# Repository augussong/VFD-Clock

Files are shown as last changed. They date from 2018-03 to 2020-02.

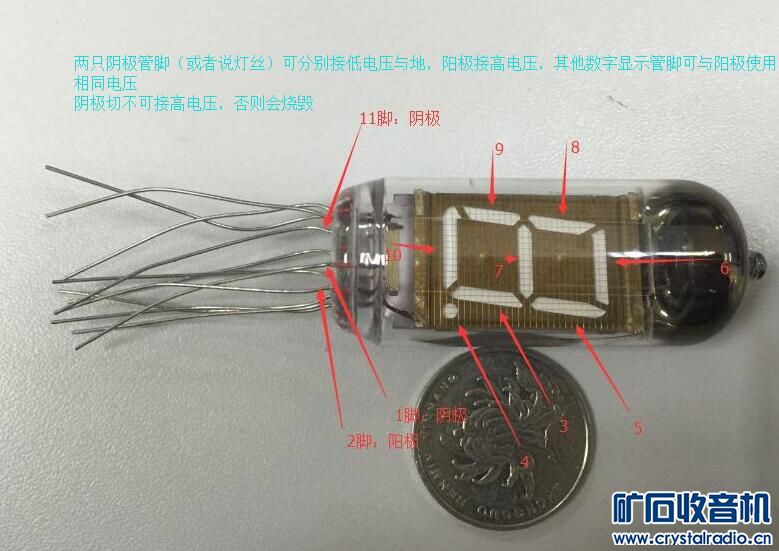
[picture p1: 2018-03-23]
Reference/管脚图.jpg

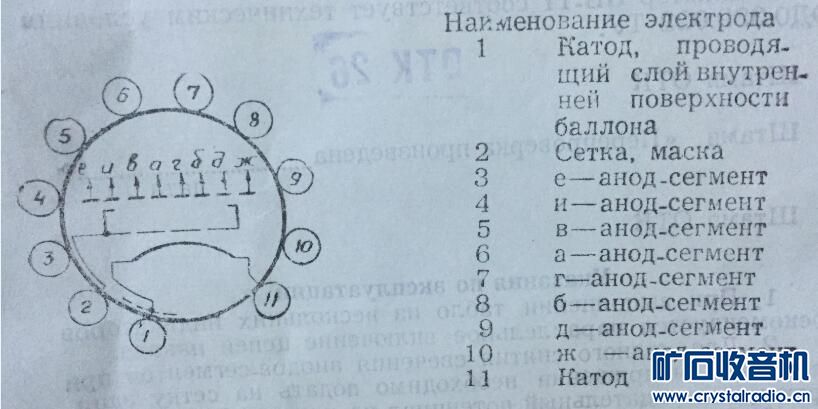
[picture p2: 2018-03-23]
Reference/管脚底视定义.jpg

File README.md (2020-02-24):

# VFD-Clock Designed By drinow
- 用IV-11制作的荧光数码管时钟

## 预计支持的功能
	1.USB连接
	2.温湿度显示
	3.RGB色彩变换
	4.静态驱动
	5.WiFi/蓝牙、红外控制
	6.uCOS-ii
	7.可以断电
	8.环境光感应

## 更新日志
- 2020.02.25更新
  - ESP8266基本功能已完成
  - 需要重新设计电源电路
  - 需要将USB更换为TYPEC，并重新调整外壳尺寸
  - 需要删除TM1812，因为无法达到100%占空比，无法实现动态驱动
- 2019.04.26更新
	+ 删除CH340晶振，并改为CH340C芯片
	+ 修改温湿度传感器位置到USB口下方
	+ 删去复位按键
	+ 其他细节调整
- 2018.03.12更新
	- 添加MCU最小系统
	- 添加了2个按键、2粒单色LED
	- 添加了串口电路、USB电路
	- 添加了部分电源电路
	- 添加了光敏电阻
	- 添加了温湿度传感器
	- 添加了6粒全彩LED
	- 添加了红外接收器

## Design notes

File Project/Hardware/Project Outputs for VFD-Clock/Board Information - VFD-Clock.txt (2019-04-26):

Board Information Report
Filename     : E:\MyData\VFD-Clock\Project\Hardware\VFD-Clock.PcbDoc
Date         : 2018/8/30
Time         : 22:43:27
Time Elapsed : 00:00:00

Routing Information
    Routing completion, 100.00%
    Connections, 522
    Connections routed, 522
    Connections remaining, 0
count : 4

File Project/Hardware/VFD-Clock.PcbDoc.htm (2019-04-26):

Altium Reporting Options

# File in Newer Format

Date | : | 2018/8/30
Time | : | 22:43:14
Filename | : | E:\MyData\VFD-Clock\Project\Hardware\VFD-Clock.PcbDoc

Version | Warning
Release 12 | CAUTION - Air Gap Width previously controlled by Clearance rule is now controlled by Polygon Connect Style rule's newly introduced Air Gap Width (set to default value). Suggest reviewing each Polygon Connect Style rule's Air Gap Width attribute for correctness.
Release 13 | CAUTION - Silk To Solder Mask Clearance Rules are converted to Silkscreen Over Component Pads Rules.
Release 14 | CAUTION - The Differential Pairs Routing rule added support for control of the width. Be aware that these widths must be manually entered as Width rules in this version.
Release 15 | CAUTION - Support of separate solder masks for top & bottom of pads added.
Release 15.1 | CAUTION - Support Multi-line PCB Text added.
Release 16.0 | CAUTION - Pad/Via hole size tolerance value added.
Release 17.0 | CAUTION - Component parameters added.
Release 17.0 | CAUTION - Support of backdrilling
Release 17.1 | CAUTION - Support of waived violations
Release 17.1 | CAUTION - Support of object specific keepouts

This file was generated by a later version of the software

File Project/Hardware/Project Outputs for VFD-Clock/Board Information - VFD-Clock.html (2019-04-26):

Altium customize

# Board Information Report

Date | : | 2018/8/30
Time | : | 22:43:27
Elapsed Time | : | 00:00:00
Filename | : | E:\MyData\VFD-Clock\Project\Hardware\VFD-Clock.PcbDoc

## Contents

Contents

Routing

Routing Information

## Routing

Routing Information
Routing completion | 100.00%
Connections | 522
Connections routed | 522
Connections remaining | 0

Back to top

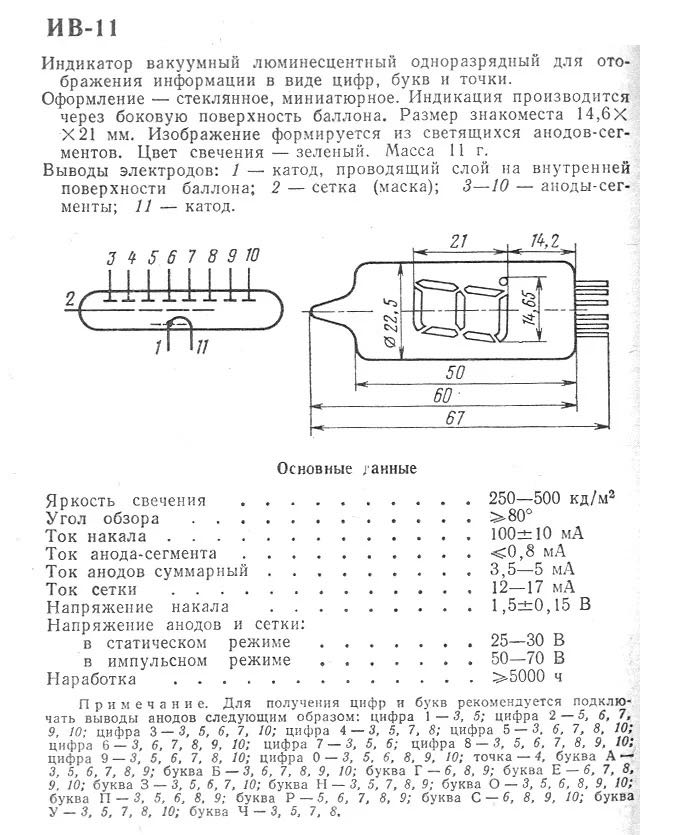
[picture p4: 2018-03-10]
Reference/IV-11引脚定义-俄文版.jpg

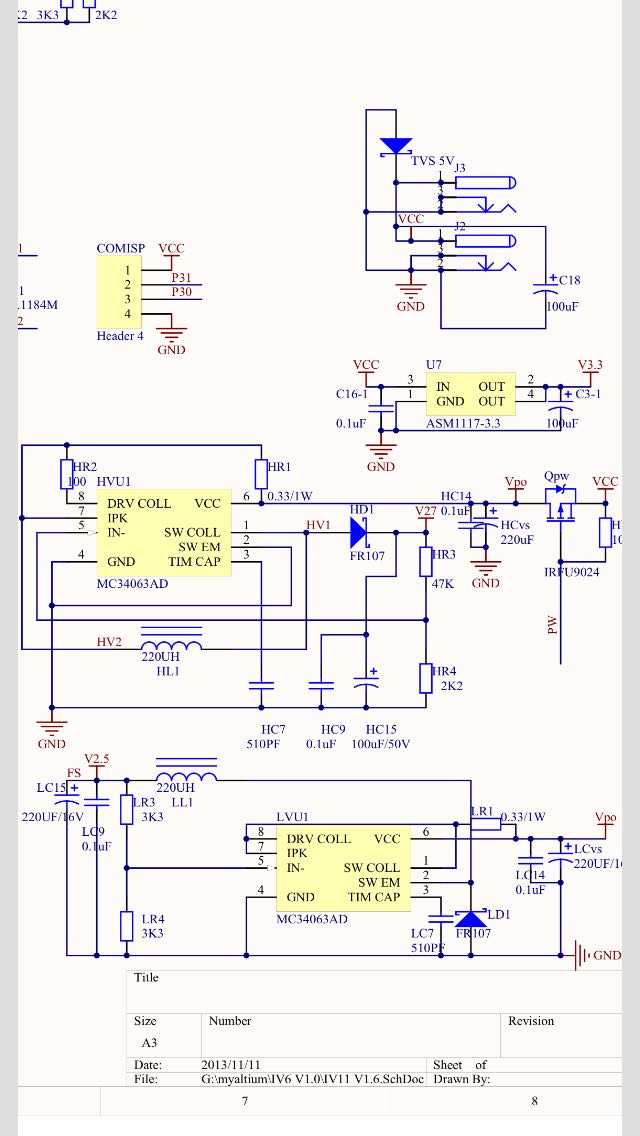
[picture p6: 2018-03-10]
Reference/供电参考.jpg

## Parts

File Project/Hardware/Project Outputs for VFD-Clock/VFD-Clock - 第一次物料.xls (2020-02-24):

Comment | Description | Designator | Footprint | Quantity
1N4148WS T4 | 二极管 | D5 | SOD-323 | 1
1.5KΩ | 贴片电阻 | R11 | 0805_R | 1
2K2 | 贴片电阻 | R10 | 0805_R | 1
8MHz | 贴片晶振 | Y1 | SMD-5032_2P | 1
47kΩ | 贴片电阻 | R7 | 0805_R | 1
100uF/35V | 极性电解电容 | C7 | CAP-7343 | 1
100Ω | 贴片电阻 | R1 | 0805_R | 1
AMS1117-3.3 | 低压差线性稳压(LDO) | VR1 | SOT-223 | 1
Battery | 备份电池 | BT1 | CR1220 | 1
BEEP | 蜂鸣器 | J2 | BEEP-SMD-8530-3V-2.7KHZ | 1
CH340C | USB | U16 | SOIC-16_150mil | 1
DS3231M+TRL | 实时时钟 | U29 | SOIC-16_300mil | 1 | DS3231SN应该更好
ESP-12S | ESP8266 串口WIFI 16Pin | U5 | ESP-12S/SMD-16 | 1
Header 2 | 接插件 | P2 | HDR2X1_A | 1
Header 4 | 接插件 | P3 | HDR4X1_A | 1
HS0038B | 红外接收器 | U13 | HS0038B | 1 | 选草帽头
JumpHat | Header, 3-Pin, Dual row | P1 | HDR2X3 | 1
SHT20 | 温湿度传感器 | *1 | DFN6 | 1
STM32F103C8T6 | ARM | U1 | LQFP-48_7x7x05P | 1
SW-PB | 微动开关 | S2 | SW_PB2_A1 | 1
USB_M | MicroUSB接口 | J1 | USB_MICRO | 1
红灯 | 发光二极管 | D1 | 0805_LED_S1 | 1
蓝灯 | 发光二极管 | D3 | 0805_LED_S1 | 1
3.3KΩ | 贴片电阻 | R16, R19 | 0805_R | 2
10Ω | 贴片电阻 | R5, R6 | 0805_R | 2
20pF | 贴片电容 | C1, C6 | 0805_C | 2
220uF/6.3V | 极性电解电容 | C11, C14 | CAP-3528 | 2
220uH | 电感 | L1, L2 | CDRH104R | 2
330mR | 贴片电阻 | R2, R15 | 1206_R | 2 | 可换小封装
470pF | 贴片电容 | C8, C17 | 0805_C | 2
A42 | 三极管 | Q1, Q2 | SOT-23(SOT-23-3) | 2
FR107 | 二极管 | D2, D4 | DIODE-SMA | 2 | 尝试用US1M、UF4007代替
MC34063A |  | U4, U6 | SOP-8 | 2
SY6288CAAC | 5V2A功率开关芯片 | U2, U3 | SOT-23-5 | 2
TM1803 | 3通道RGB全彩驱动芯片 | U14, U15 | SOP-8 | 2 | WS2811代替
10KΩ | 贴片电阻 | R3, R4, R13 | 0805_R | 3
4.7KΩ (472) ±5% | 贴片排阻 | Rp1, Rp2, Rp3, Rp4 | 0603_Rx4 | 4
10uF | 贴片电容 | C3, C4, C13, C20, C21 | 0805_C | 5
M3铜柱螺丝孔 |  | T1, T2, T3, T4, T5 | 螺丝孔-3mm | 5
74HC595D | 74系列逻辑芯片 | U17, U18, U19, U20, U21, U22 | SOIC-16_150mil | 6
IV-11 | 荧光数码管 | Tube1, Tube2, Tube3, Tube4, Tube5, Tube6 | IV-11-1 | 6
ULN2803ADW | 大电流驱动 | U23, U24, U25, U26, U27, U28 | SOIC-18_300mil | 6
WS2812-LED |  | U7, U8, U9, U10, U11, U12 | WS2812 | 6
1KΩ | 贴片电阻 | R8, R9, R12, R14, R17, R18, R20, R21 | 0805_R | 8
4.7KΩ | 贴片排阻 | Rp5, Rp6, Rp7, Rp8, Rp9, Rp10, Rp11, Rp12, Rp13, Rp14, Rp15, Rp16 | 0603_Rx4 | 12
100nF | 贴片电容 | C2, C5, C9, C10, C12, C15, C16, C18, C19, C22, C23, C24, C25, C26, C27, C28, C29, C30, C31, C32, C33 | 0805_C | 21

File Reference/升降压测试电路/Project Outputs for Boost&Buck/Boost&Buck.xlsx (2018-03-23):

Comment | Description | Designator | Footprint | Quantity
MC34063A |  | *1, *2 | SOP-8 | 2
220uF/16V | 极性电解电容 | C1, C6, C8 | 6mm贴片铝电解电容 | 3
100nF | 贴片电容 | C2, C5, C7, C9 | 0805_C | 4
100uF/50V | 极性电解电容 | C3 | 8mm贴片铝电解电容 | 1
510pF | 贴片电容 | C4, C10 | 0805_C | 2
FR107 | 二极管 | D1, D2, D3 | DIODE-SMA | 3
USB | USB接口 | J1, J2 | USB_A1母座直插 | 2
220uH | 电感 | L1, L2 | CDRH104R | 2
Header 4 | Header, 4-Pin | P1, P2, P3 | HDR1X4 | 3
100Ω | 贴片电阻 | R1 | 0805_R | 1
330mR | 贴片电阻 | R2, R5 | 1206_R | 2
47kΩ | 贴片电阻 | R3 | 0805_R | 1
2K2 | 贴片电阻 | R4 | 0805_R | 1
3.3KΩ | 贴片电阻 | R6, R7 | 0805_R | 2
470pF | 贴片电容 | C4, C10 | 0805_C | 2

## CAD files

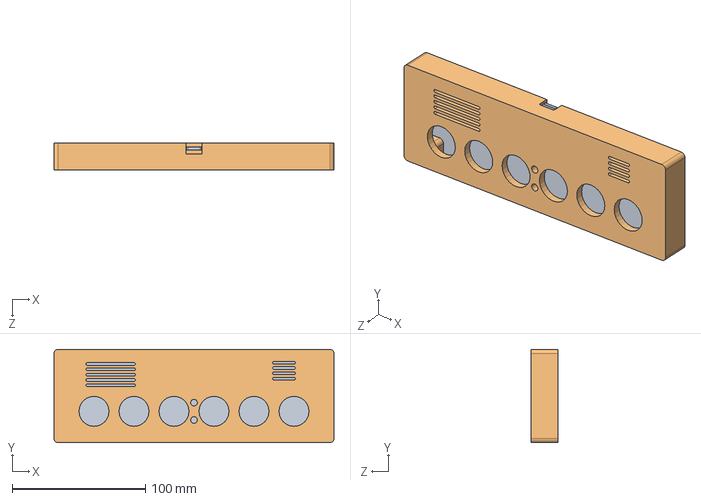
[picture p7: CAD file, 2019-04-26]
Project/Model/各部分/装配体1.SLDASM
210.0 x 70.0 x 20.0 mm
电路样板
一体化框架-木

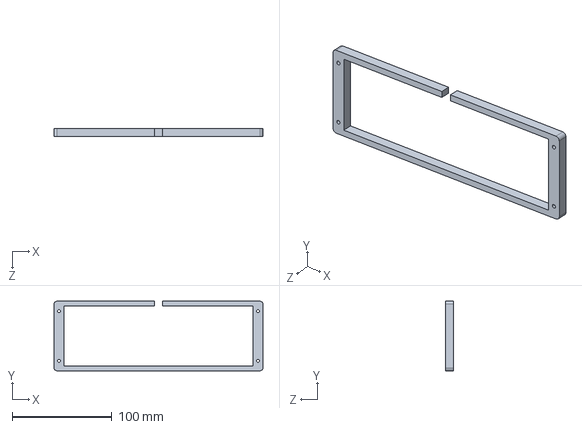
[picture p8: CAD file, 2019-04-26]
Project/Model/各部分/中间框架.SLDPRT
210.0 x 70.0 x 8.00 mm

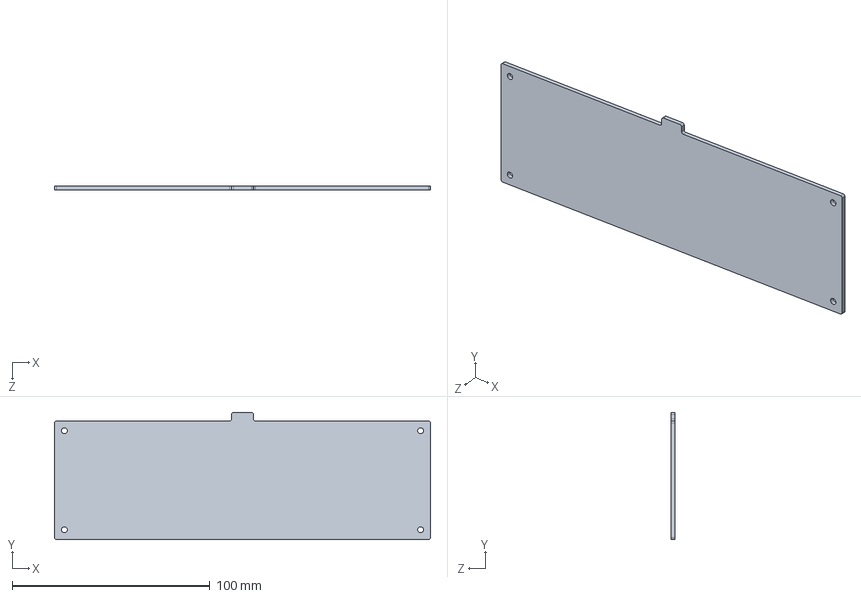
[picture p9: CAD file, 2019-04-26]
Project/Model/各部分/电路样板.SLDPRT
190.0 x 64.3 x 2.00 mm

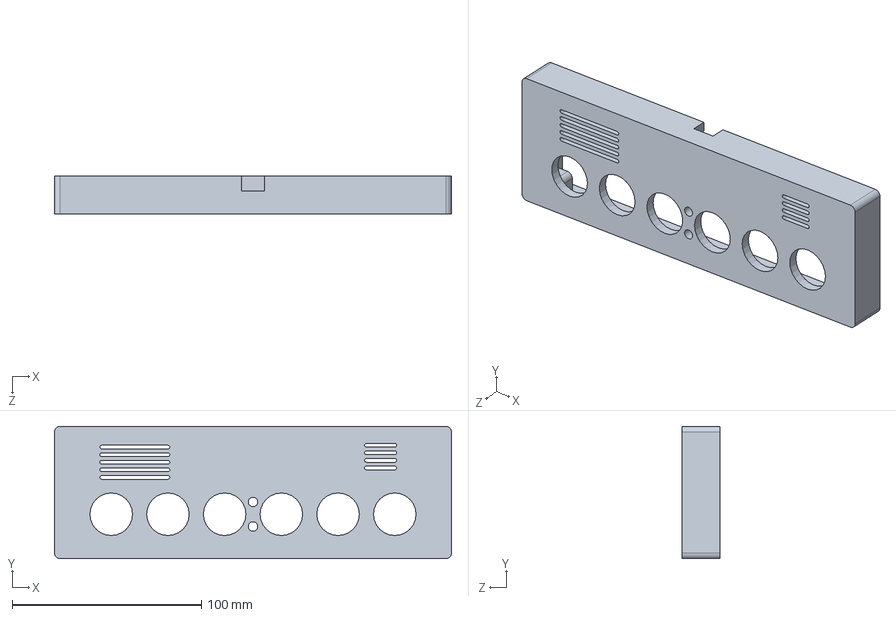
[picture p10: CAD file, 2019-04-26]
Project/Model/各部分/一体化框架-木.SLDPRT
210.0 x 70.0 x 20.0 mm

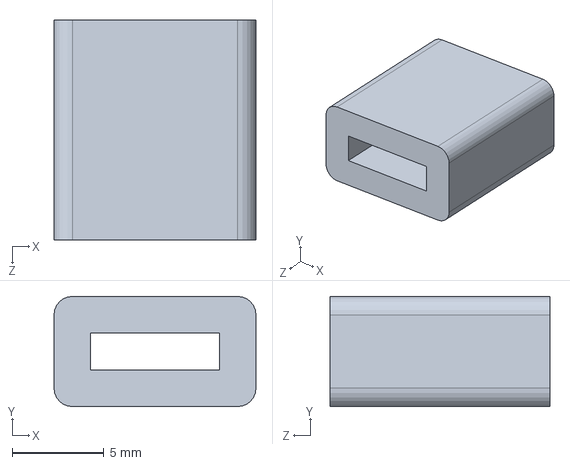
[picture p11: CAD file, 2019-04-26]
Project/Model/各部分/传感器支架.SLDPRT
11.0 x 6.00 x 12.0 mm

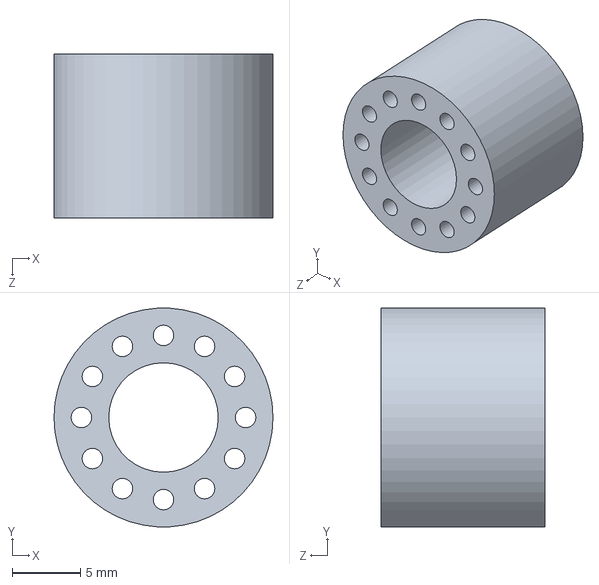
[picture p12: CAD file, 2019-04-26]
Project/Model/各部分/管子支架.SLDPRT
16.0 x 16.0 x 12.0 mm

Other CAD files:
Project/Model/各部分 - 新/传感器支架.DWG
Project/Model/定位-不可直接用因为有些工艺做不到.SLDPRT
Project/Model/各部分 - 新/管子支架.DWG
Project/Model/各部分/上面板 无散热孔.DWG
Project/Model/各部分/上盖板 - 扩.DWG
Project/Model/各部分/下盖板 - 扩.DWG
Project/Model/各部分/上盖板 - 扩 - 不带螺丝孔.DWG
Project/Model/各部分/框架二维图.dwg
Project/Model/各部分/上面板.DWG
Project/Model/各部分/一体化框架.DWG
Project/Model/各部分/下面板.DWG
Project/Model/各部分/一体化框架-木.DWG
Project/Model/各部分/一体化框架工程图-木.SLDDRW
Project/Model/各部分/一体化框架工程图.SLDDRW
Project/Model/各部分/中间框架.DWG
Project/Model/各部分/中间框架工程图.SLDDRW
Project/Model/各部分/电路样板.DWG

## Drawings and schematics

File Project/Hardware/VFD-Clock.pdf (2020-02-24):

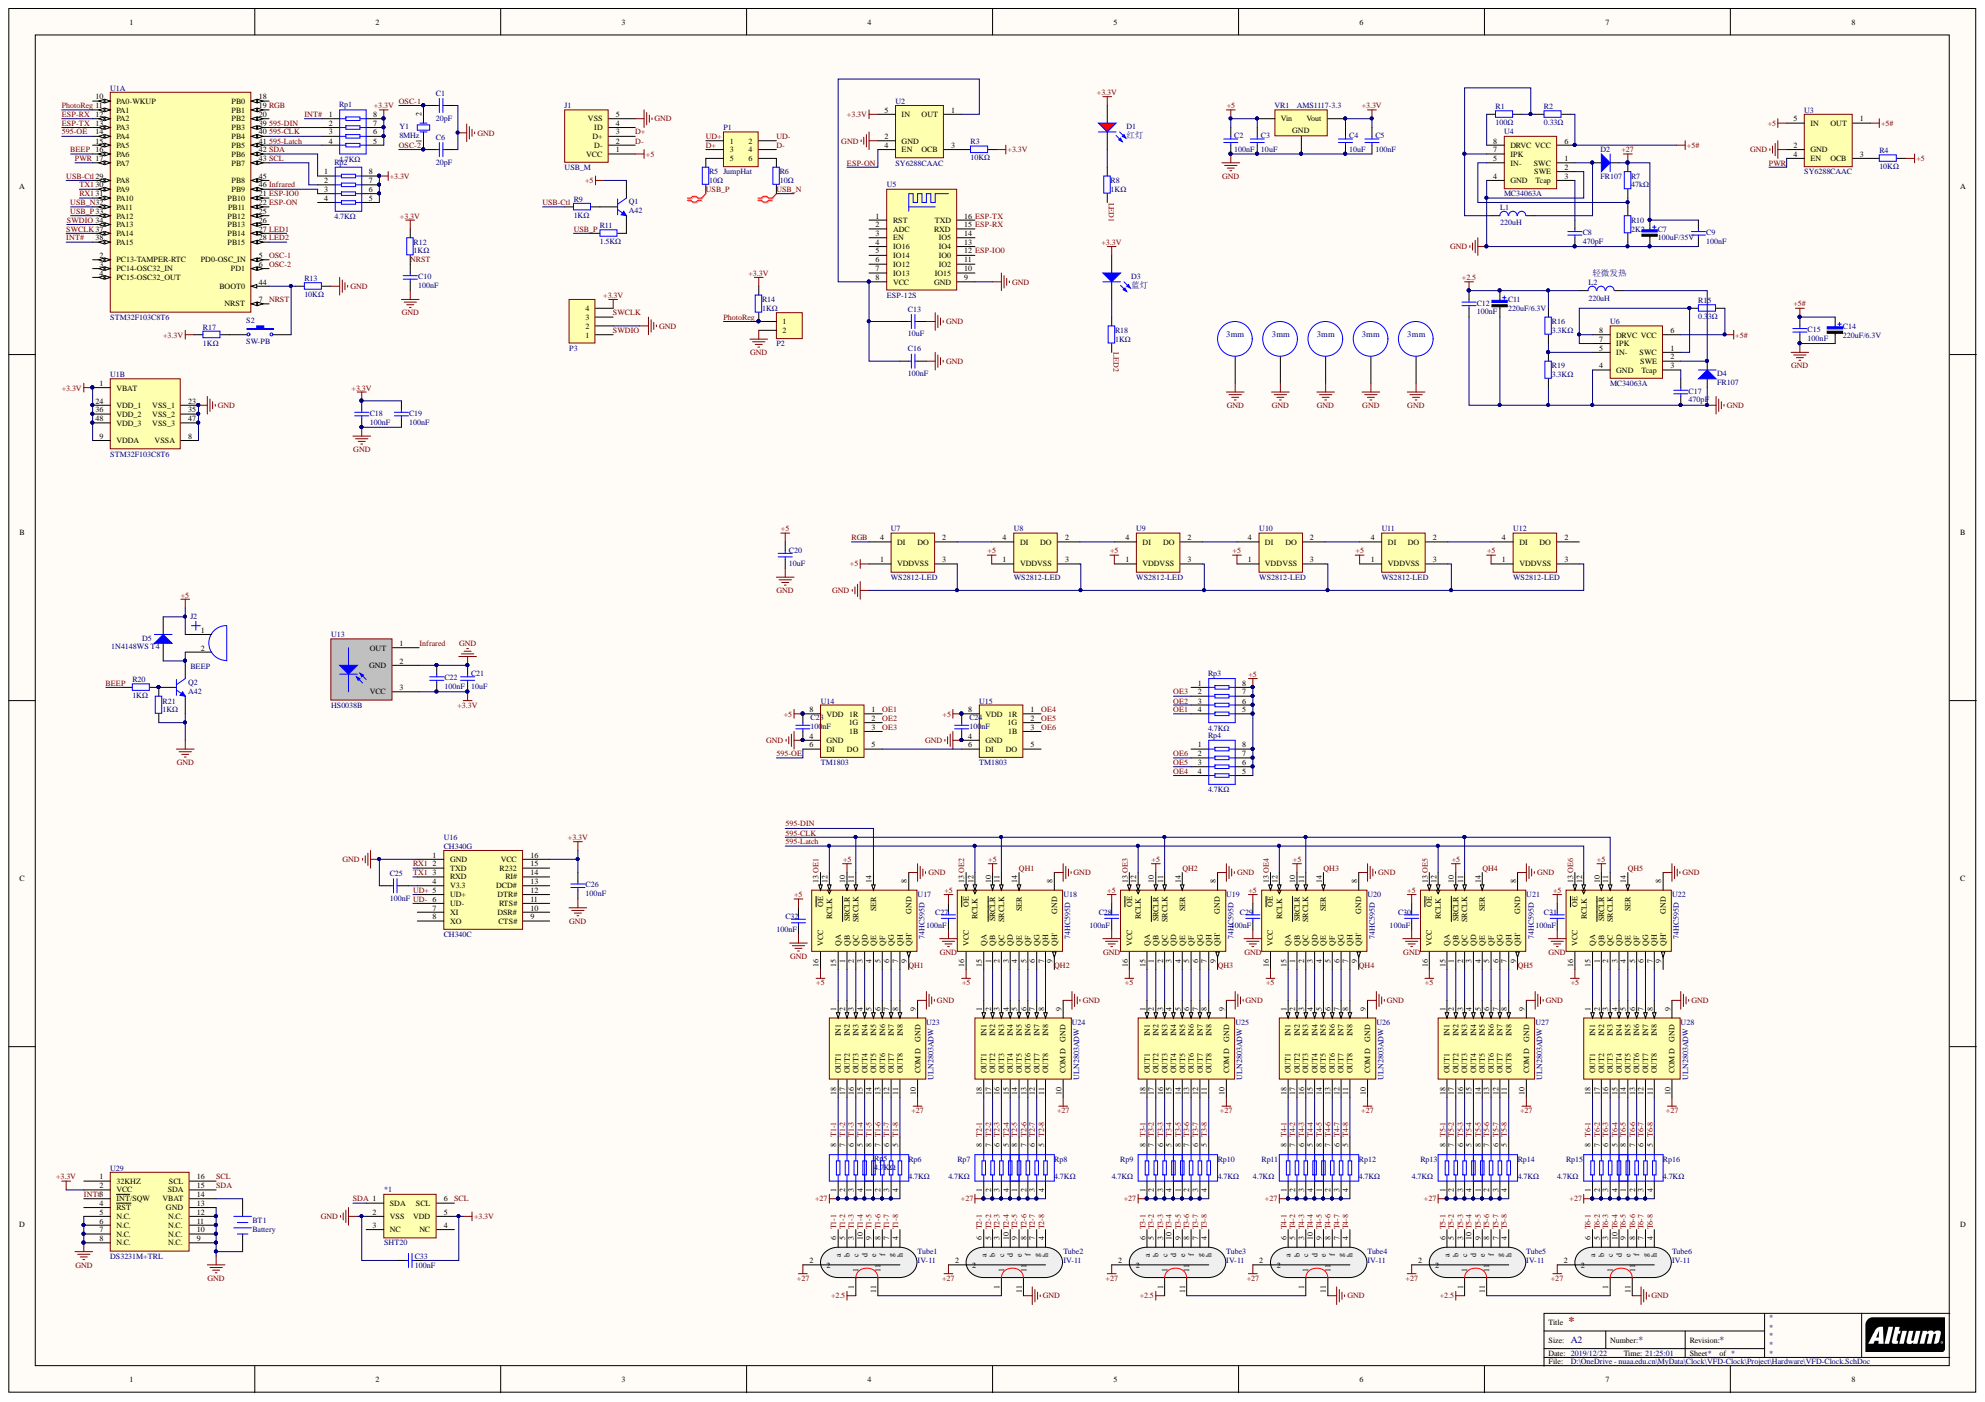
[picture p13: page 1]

C25 | RX1 | TXD 2

* Title | * * * * *

Size: A2 | Number: * | Revision: *

Date: 2019/12/22 Time: 21:25:01 | | Sheet * of *

D:\OneDrive - nuaa.edu.cn\MyData\Clock\VFD-Clock\Project\Hardware\VFD-Clock.SchDoc

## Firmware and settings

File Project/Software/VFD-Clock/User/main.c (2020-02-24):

/**
  ******************************************************************************
  * @file    main.c
  * @author  inhowe
  * @version 
  * @date    
  * @brief   
  ******************************************************************************
  * @attention
  *
  *
  ******************************************************************************
  */
  
#include "includes.h"


OS_TCB	StartUp_TCB;		   					          //定义任务控制块
CPU_STK	StartUp_Stk[STARTUP_TASK_STK_SIZE];		//定义任务堆栈

/**
  * @brief  主函数
  * @param  无
  * @retval 无
  */
int main(void)
{
  OS_ERR err;	

  /* 板级初始化 */	
	BSP_Init();
	
  /* 初始化"uC/OS-III"内核 */  
	OSInit(&err);		                                        
  
	/*创建任务*/
	OSTaskCreate((OS_TCB     *)&StartUp_TCB,                // 任务控制块指针          
               (CPU_CHAR   *)"StartUp",		                // 任务名称
               (OS_TASK_PTR )Task_Start, 	                // 任务代码指针
               (void       *)0,			                      // 传递给任务的参数parg
               (OS_PRIO     )STARTUP_TASK_PRIO,			      // 任务优先级
               (CPU_STK    *)&StartUp_Stk[0],	            // 任务堆栈基地址
               (CPU_STK_SIZE)STARTUP_TASK_STK_SIZE/10,	  // 堆栈剩余警戒线
               (CPU_STK_SIZE)STARTUP_TASK_STK_SIZE,			  // 堆栈大小
               (OS_MSG_QTY  )0,			                      // 可接收的最大消息队列数
               (OS_TICK     )0,			                      // 时间片轮转时间
               (void       *)0,			                      // 任务控制块扩展信息
               (OS_OPT      )(OS_OPT_TASK_STK_CHK | 
                              OS_OPT_TASK_STK_CLR),	      // 任务选项
               (OS_ERR     *)&err);		                    // 返回值
	
	/* 启动节拍器 */
	SysTick_Init();  
  /* 启动多任务系统，控制权交给uC/OS-II */
  OSStart(&err);  
	                                   
}

/*********************************************END OF FILE**********************/

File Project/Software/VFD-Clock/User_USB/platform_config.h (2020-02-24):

/******************** (C) COPYRIGHT 2009 STMicroelectronics ********************
* File Name          : platform_config.h
* Author             : MCD Application Team
* Version            : V3.0.1
* Date               : 04/27/2009
* Description        : Evaluation board specific configuration file.
********************************************************************************
* THE PRESENT FIRMWARE WHICH IS FOR GUIDANCE ONLY AIMS AT PROVIDING CUSTOMERS
* WITH CODING INFORMATION REGARDING THEIR PRODUCTS IN ORDER FOR THEM TO SAVE TIME.
* AS A RESULT, STMICROELECTRONICS SHALL NOT BE HELD LIABLE FOR ANY DIRECT,
* INDIRECT OR CONSEQUENTIAL DAMAGES WITH RESPECT TO ANY CLAIMS ARISING FROM THE
* CONTENT OF SUCH FIRMWARE AND/OR THE USE MADE BY CUSTOMERS OF THE CODING
* INFORMATION CONTAINED HEREIN IN CONNECTION WITH THEIR PRODUCTS.
*******************************************************************************/

/* Define to prevent recursive inclusion -------------------------------------*/
#ifndef __PLATFORM_CONFIG_H
#define __PLATFORM_CONFIG_H

/* Includes ------------------------------------------------------------------*/
#include "stm32f10x.h"

/* Exported types ------------------------------------------------------------*/
/* Exported constants --------------------------------------------------------*/
/* Uncomment the line corresponding to the STMicroelectronics evaluation board
   used to run the example */
#if !defined (USE_STM3210B_EVAL) &&  !defined (USE_STM3210E_EVAL)
 #define USE_STM3210B_EVAL
 //#define USE_STM3210E_EVAL
#endif

/* Define the STM32F10x hardware depending on the used evaluation board */
#ifdef USE_STM3210B_EVAL

  #define USB_DISCONNECT											GPIOA  
  #define USB_DISCONNECT_PIN									GPIO_Pin_8
  #define RCC_APB2Periph_GPIO_DISCONNECT      RCC_APB2Periph_GPIOA
	#define USB_GPIO_MODE												GPIO_Mode_Out_PP
	
	#define 	 CONNECT_CABLE()			GPIO_SetBits(USB_DISCONNECT, USB_DISCONNECT_PIN);
	#define DISCONNECT_CABLE()			GPIO_ResetBits(USB_DISCONNECT, USB_DISCONNECT_PIN);

#else /* USE_STM3210E_EVAL */

  #define USB_DISCONNECT            GPIOB  
  #define USB_DISCONNECT_PIN        GPIO_Pin_14
  #define RCC_APB2Periph_GPIO_DISCONNECT      RCC_APB2Periph_GPIOB

#endif /* USE_STM3210B_EVAL */

/* Exported macro ------------------------------------------------------------*/
/* Exported functions ------------------------------------------------------- */

#endif /* __PLATFORM_CONFIG_H */

/******************* (C) COPYRIGHT 2009 STMicroelectronics *****END OF FILE****/

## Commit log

2018-03-10 建立一个新的工程
2018-03-10 修改README和gitignore
2018-03-12 添加了一些电路
    [VFD-Clock.SchDoc]
2020-02-24 电源要重新设计、要换typec口、要调整外壳尺寸、增加8266基本功能
    [VFD-Clock - 第一次物料.xls, VFD-Clock.PrjPcb, VFD-Clock.SchDoc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]
